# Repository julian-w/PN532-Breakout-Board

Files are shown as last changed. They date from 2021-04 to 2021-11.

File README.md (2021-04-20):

# PN532-Breakout-Board
Breakout-Board for the PN532 with improved RFID antenna

original Layout: https://github.com/adafruit/Adafruit-PN532-RFID-NFC-Breakout

## Changes

- Removed copper under the antenna and flipped the antenna to the other side
- Shrinked board and added additional mounting holes
- Removed mostly unneeded breakout pins
- All components are SMD to allow a flat back
- Added BOM

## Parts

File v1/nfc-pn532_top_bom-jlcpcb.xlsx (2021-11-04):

Column1 | Column2 | Column3 | Column4
Comment | Designator | Footprint | LCSC Part #
0.1ÂµF | C11 C14 C16 C17 C18 C20 C23 C24 | 0805-NO | C49678
1.0K | R1 | 0805-NO | C17513
1.5 | R3 R4 | 0805-NO
10k | R7 | 0805-NO | C17414
1.69K | R2 | 0805-NO
10ÂµF | C19 C21 C22 C25 C26 C27 | 0805-NO | C15850
22pF | C1 C2 | 0805-NO | C1804
27.12MHz | Y1 | CRYSTAL_3.2X2.5 | C113669
33pF | C12 C13 | 0805-NO | C1792
100pF | C7 C8 | 0805-NO | C1790
220pF | C3 C4 | 0805-NO | C53172
560nH | L3 L6 | L1008CS
1000pF | C15 | 0805-NO | C46653
FERRITE | L1 L2 | 0805 | C81034
GREEN | LED1 | CHIPLED_0805_NOOUTLINE | C2297
MIC5225-3.3V | U2 | SOT23-5 | C512101
NC | C5 C6 C9 C10 | 0805-NO
PN532 | U1 | HVQFN40-6X6 | C28925
RX | TP7 | TESTPOINT_ROUND_1MM
TBD | R8 | 0805-NO
TGND | TP2 TP6 | TESTPOINT_ROUND_1MM
TX1_POST | TP1 | TESTPOINT_ROUND_1MM
TX1_PRE | TP5 | TESTPOINT_ROUND_1MM
TX2_POST | TP3 | TESTPOINT_ROUND_1MM
TX2_PRE | TP4 | TESTPOINT_ROUND_1MM

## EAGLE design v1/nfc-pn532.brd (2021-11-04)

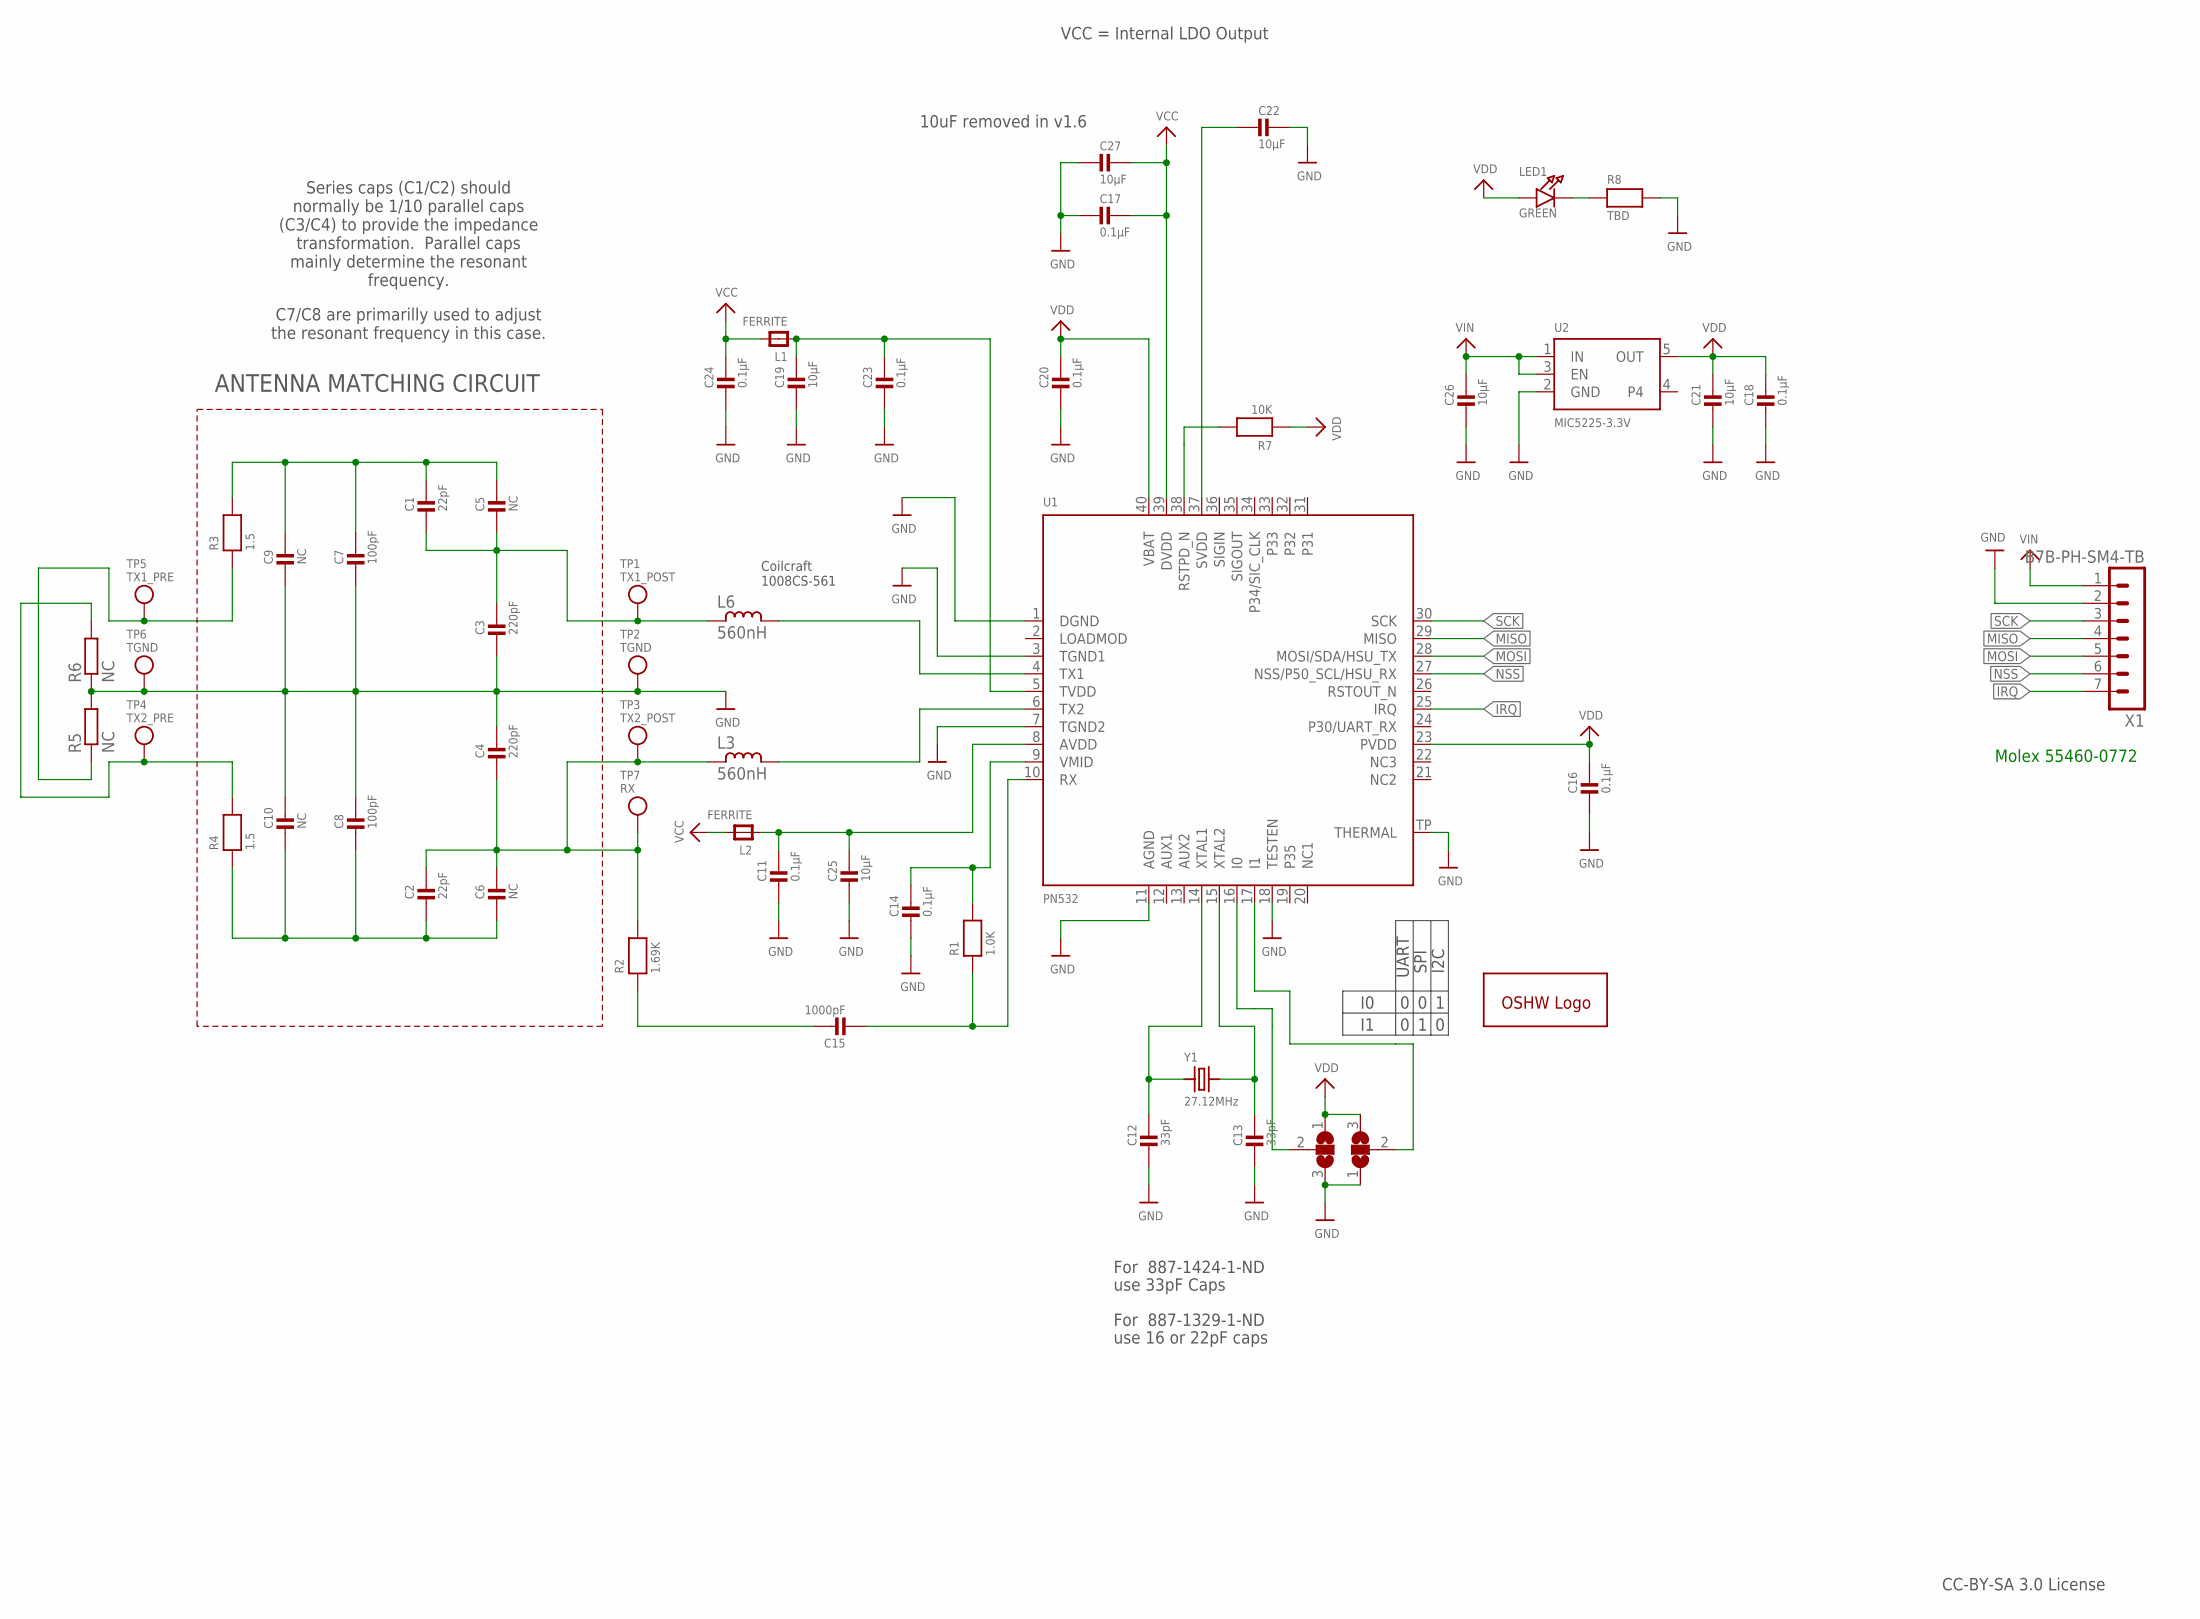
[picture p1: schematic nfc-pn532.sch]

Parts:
C1, C2: 22pF; 0805-NO
C3, C4: 220pF; 0805-NO
C5, C6, C9, C10: NC; 0805-NO
C7, C8: 100pF; 0805-NO
C11, C14, C16, C17, C18, C20, C23, C24: 0.1µF; 0805-NO
C12, C13: 33pF; 0805-NO
C15: 1000pF; 0805-NO
C19, C21, C22, C25, C26, C27: 10µF; 0805-NO
GOLD_ORB_SM1: OSHWLOGOLOGO5MM; OSHW_5MM
L1, L2: FERRITE; 0805
L3, L6: 560nH; L1008CS
LED1: GREEN; CHIPLED_0805_NOOUTLINE
R1: 1.0K; 0805-NO
R2: 1.69K; 0805-NO
R3, R4: 1.5; 0805-NO
R5, R6: NC; R0201
R7: 10K; 0805-NO
R8: TBD; 0805-NO
SJ1, SJ2: SJ2W; SJ_2
TP1: TX1_POST; TESTPOINT_ROUND_1MM
TP2, TP6: TGND; TESTPOINT_ROUND_1MM
TP3: TX2_POST; TESTPOINT_ROUND_1MM
TP4: TX2_PRE; TESTPOINT_ROUND_1MM
TP5: TX1_PRE; TESTPOINT_ROUND_1MM
TP7: RX; TESTPOINT_ROUND_1MM
U1: PN532; HVQFN40-6X6
U2: MIC5225-3.3V; SOT23-5
X1: B7B-PH-SM4-TB
Y1: 27.12MHz; CRYSTAL_3.2X2.5

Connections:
+5.0V: C26.1, U2.1 (IN), U2.3 (EN), X1.1
GND: C3.2, C4.1, C7.2, C8.1, C9.2, C10.1, C11.2, C12.2, C13.2, C14.2, C16.2, C17.2, C18.2, C19.2, C20.2, C21.2, C22.1, C23.2, C24.2, C25.2, C26.2, C27.2, R5.2, R6.1, R8.2, SJ1.3, SJ2.1, TP2.P$1, TP6.P$1, U1.1 (DGND), U1.3 (TGND1), U1.7 (TGND2), U1.11 (AGND), U1.18 (TESTEN), U1.TP (THERMAL), U2.2 (GND), X1.2
IRQ: U1.25 (IRQ), X1.7
MISO: U1.29 (MISO), X1.4
MOSI: U1.28 (MOSI/SDA/HSU_TX), X1.5
unnamed: L6.2, U1.4 (TX1)
unnamed: L3.2, U1.6 (TX2)
unnamed: C1.2, C3.1, C5.2, L6.1, TP1.P$1
unnamed: SJ1.2, U1.16 (I0)
unnamed: SJ2.2, U1.17 (I1)
unnamed: LED1.C, R8.1
unnamed: C12.1, U1.14 (XTAL1), Y1.1
unnamed: C13.1, U1.15 (XTAL2), Y1.2
unnamed: C15.1, R2.1
unnamed: C14.1, R1.2, U1.9 (VMID)
unnamed: C15.2, R1.1, U1.10 (RX)
unnamed: C2.1, C4.2, C6.1, L3.1, R2.2, TP3.P$1, TP7.P$1
unnamed: C11.1, C25.1, L2.1, U1.8 (AVDD)
unnamed: C19.1, C23.1, L1.1, U1.5 (TVDD)
unnamed: C22.2, U1.37 (SVDD)
unnamed: R3.1, R5.1, TP5.P$1
unnamed: R4.2, R6.2, TP4.P$1
NSS: U1.27 (NSS/P50_SCL/HSU_RX), X1.6
RSTPD_N: R7.2, U1.38 (RSTPD_N)
SCK: U1.30 (SCK), X1.3
TX1_ANTENNA: C1.1, C5.1, C7.1, C9.1, R3.2
TX2_ANTENNA: C2.2, C6.2, C8.2, C10.2, R4.1
VCC: C17.1, C24.1, C27.1, L1.2, L2.2, U1.39 (DVDD)
VDD: C16.1, C18.1, C20.1, C21.1, LED1.A, R7.1, SJ1.1, SJ2.3, U1.23 (PVDD), U1.40 (VBAT), U2.5 (OUT)

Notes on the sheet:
ANTENNA MATCHING CIRCUIT
UART
SPI
I2C
CC-BY-SA 3.0 License
For 887-1329-1-ND
use 16 or 22pF caps
For 887-1424-1-ND
use 33pF Caps
VCC = Internal LDO Output
Series caps (C1/C2) should normally be 1/10 parallel caps (C3/C4) to provide the impedance transformation. Parallel caps mainly determine the resonant frequency.
C7/C8 are primarilly used to adjust the resonant frequency in this case.
Coilcraft 1008CS-561
10uF removed in v1.6
Molex 55460-0772

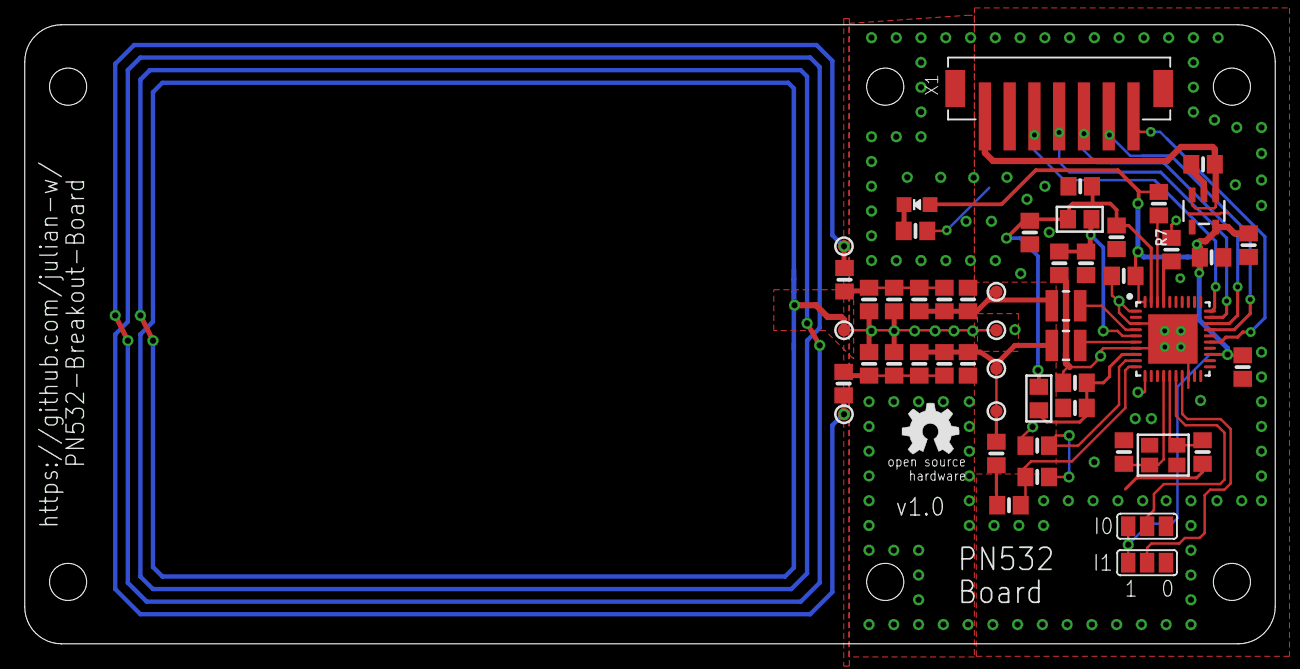
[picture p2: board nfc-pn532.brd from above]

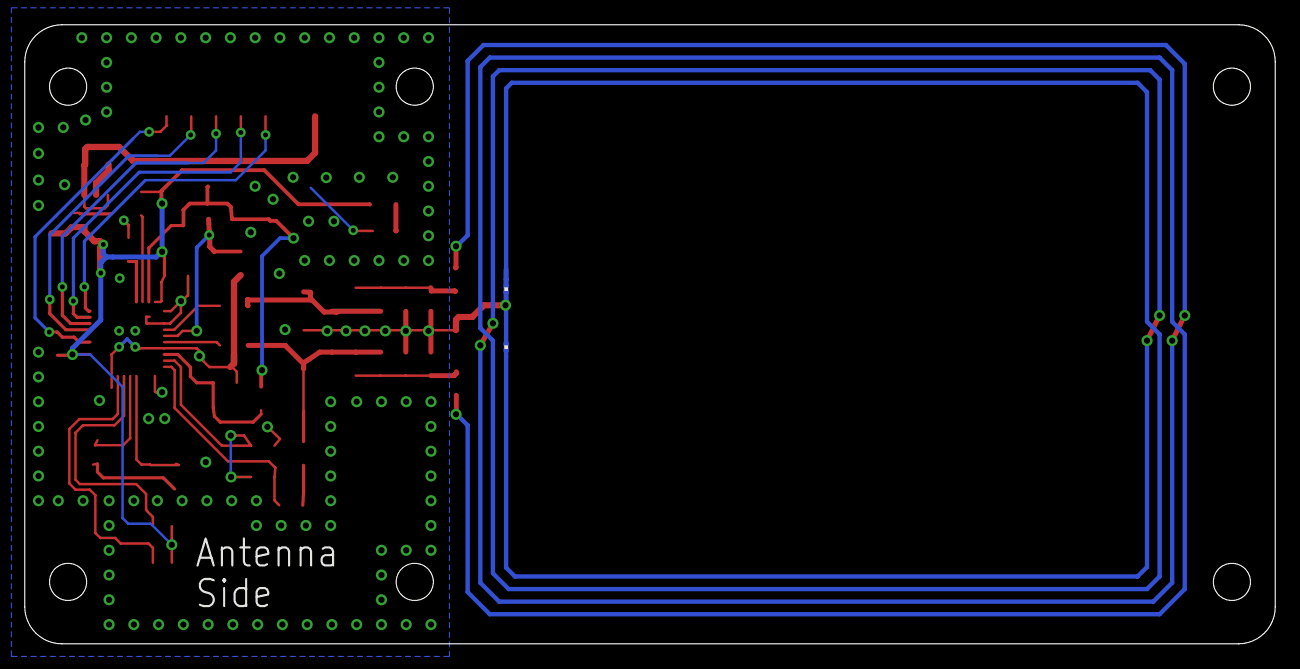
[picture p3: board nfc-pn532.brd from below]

Board: 2 copper layers, 101.0 x 50.0 mm, 54 parts (2 on the bottom side), 29 nets.

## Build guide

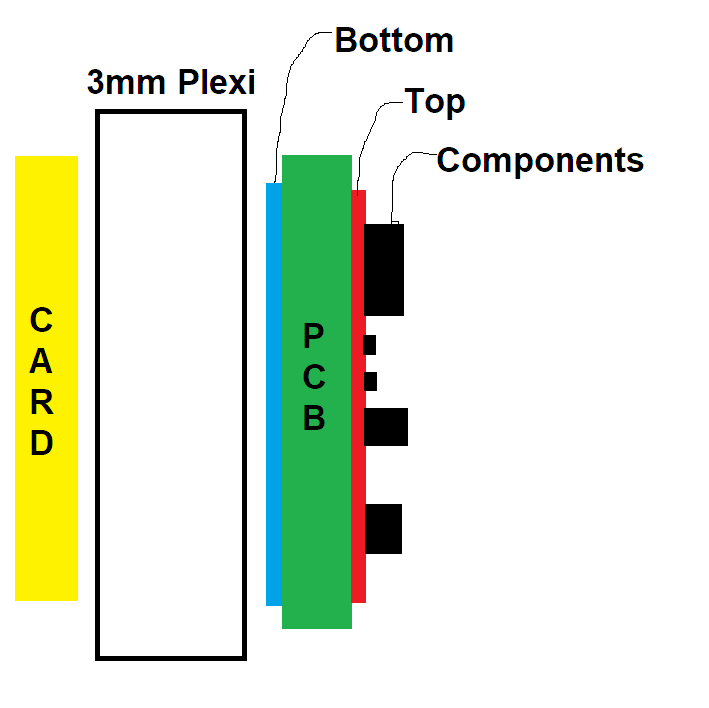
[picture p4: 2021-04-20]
v1/aufbau.png

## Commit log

2021-04-20 adding v1 with JLCPCB production files
    [nfc-pn532-old.brd, nfc-pn532-old.sch, nfc-pn532.brd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]
2021-11-04 updating schematic
    [nfc-pn532.brd, nfc-pn532.sch, nfc-pn532_top_bom-jlcpcb.xlsx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]
